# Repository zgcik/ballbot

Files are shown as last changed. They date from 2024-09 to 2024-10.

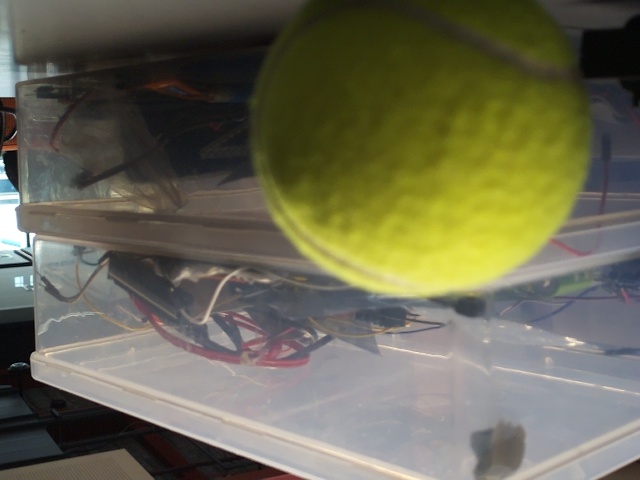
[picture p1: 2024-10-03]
test.jpg

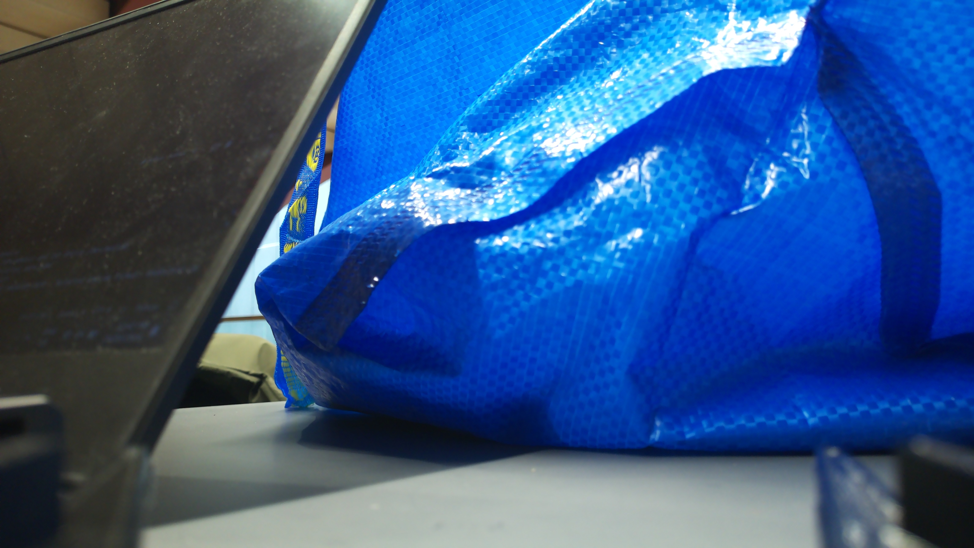
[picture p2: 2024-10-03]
image.jpg

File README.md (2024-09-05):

# ballcollector
ece4191 project overview:

synopsis:
- be able to locate tennis balls contained within its quadrant of the court
- be able to move to a located tennis ball
- be able to pick up located tennis balls
- be able to navigate to a collection box located in the center of the four quadrants of the court
- be able to deposit collected tennis balls in the cardboard collection box of dimensions 60x45x18cm
- may travel into other quadrants of the court momentarily

## Pi Setup

environment initialisation:

```sh
sudo apt-get update && sudo apt-get upgrade -y
sudo apt-get install -y git libgl1
```

To install Python packages:

```sh
python3.11 -m venv .venv
. .venv/bin/activate
pip install -r requirements.txt
```

To get proper headless opencv

```sh
pip uninstall opencv-python && pip install opencv-python-headless==4.10.0.84
```

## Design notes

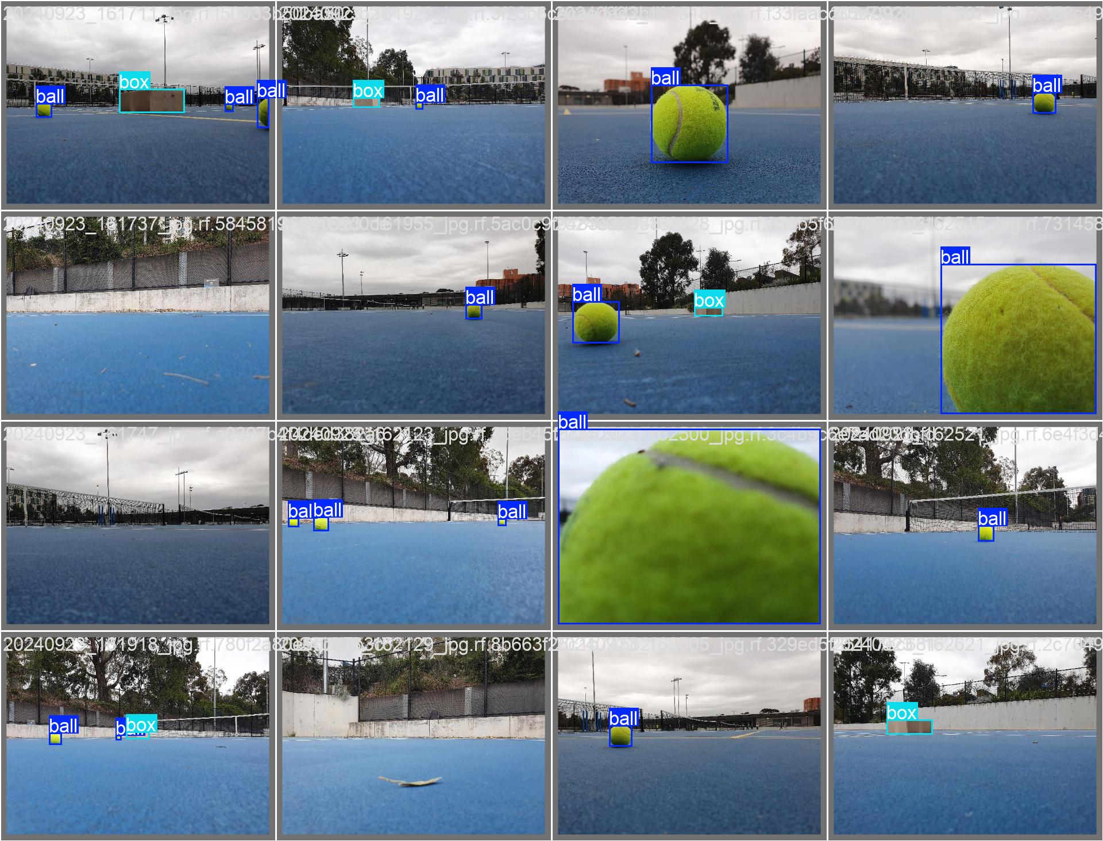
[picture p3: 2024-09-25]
runs/detect/train15/val_batch1_labels.jpg

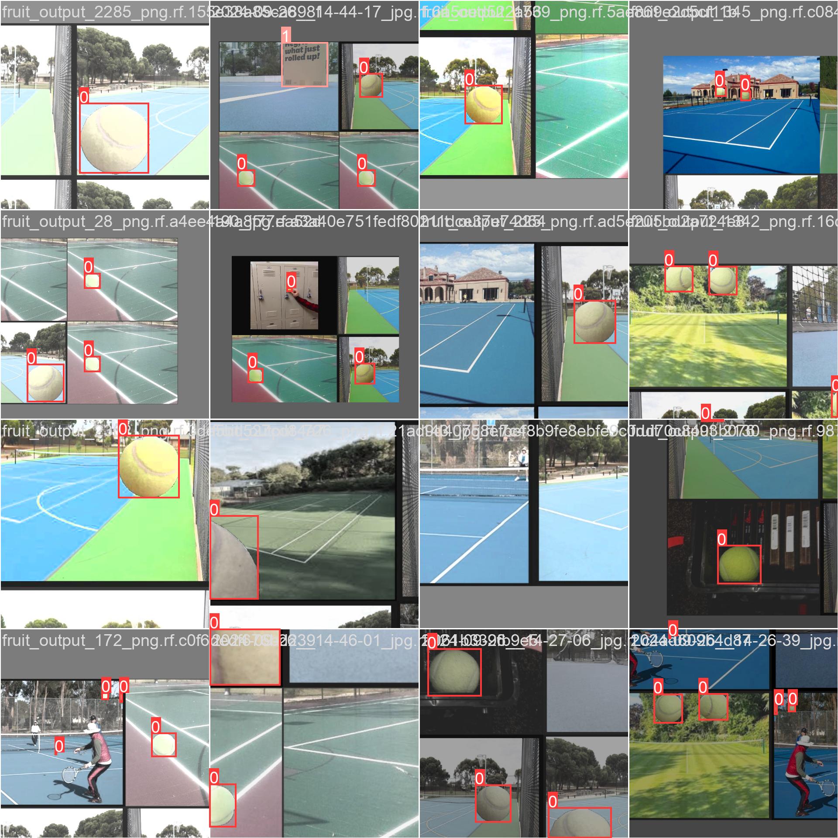
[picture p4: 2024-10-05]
runs/detect/train7/train_batch1.jpg

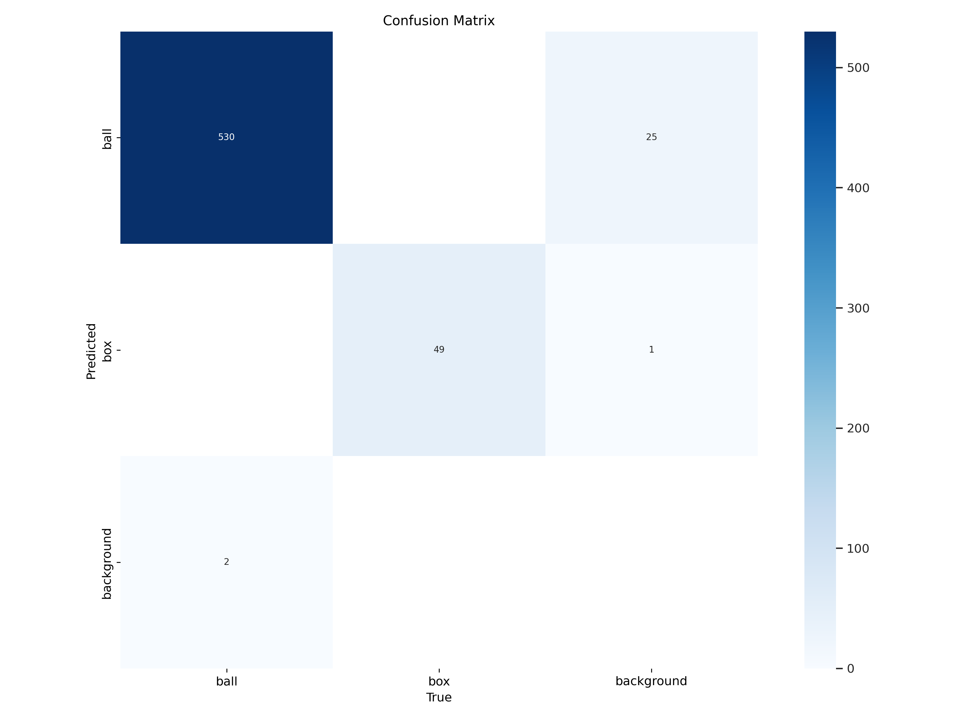
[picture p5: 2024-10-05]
runs/detect/train/confusion_matrix.png

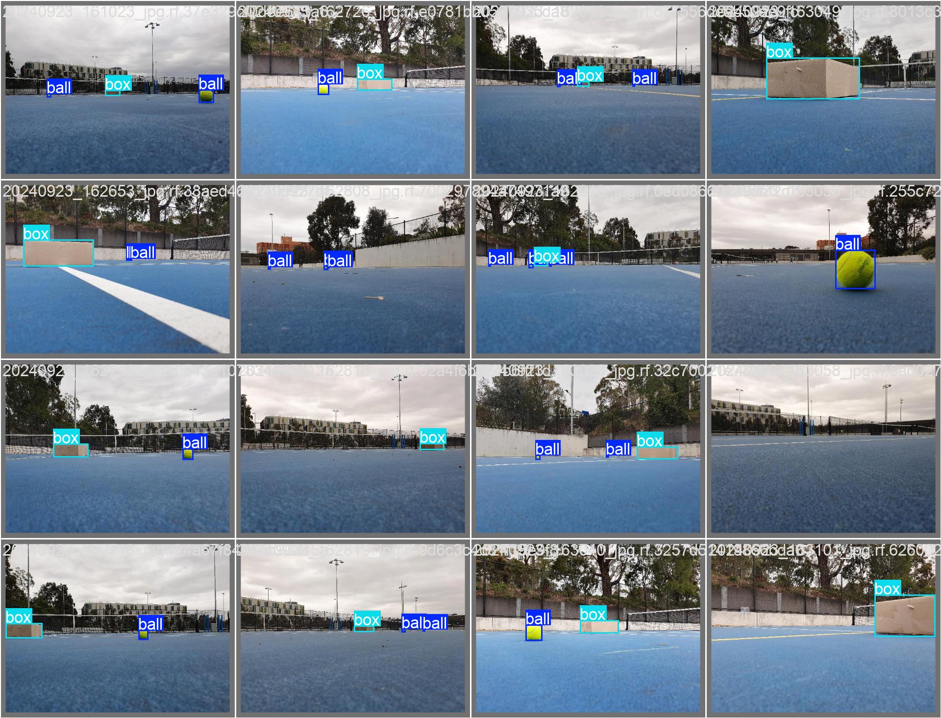
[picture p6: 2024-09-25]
runs/detect/train15/val_batch0_labels.jpg

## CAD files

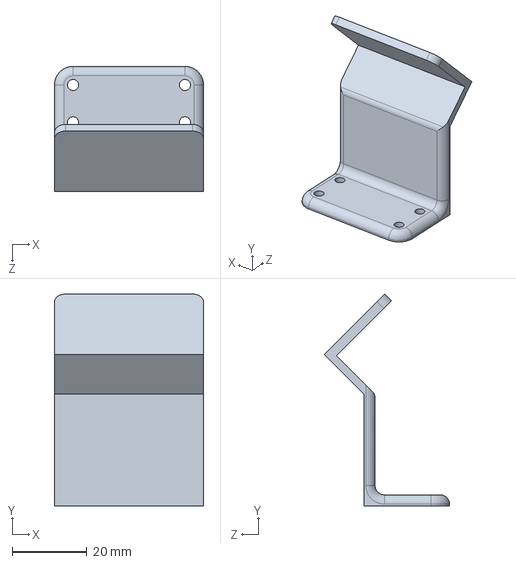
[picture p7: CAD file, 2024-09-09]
cad/camera_mount.SLDPRT
40.0 x 56.9 x 33.6 mm

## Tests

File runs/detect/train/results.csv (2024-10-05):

epoch | train/box_loss | train/cls_loss | train/dfl_loss | metrics/precision(B) | metrics/recall(B) | metrics/mAP50(B) | metrics/mAP50-95(B) | val/box_loss | val/cls_loss | val/dfl_loss | lr/pg0 | lr/pg1 | lr/pg2
1 | 0.61367 | 0.33842 | 0.95513 | 0.99523 | 0.97931 | 0.99433 | 0.86966 | 0.64935 | 0.30115 | 0.94216 | 0.003325 | 0.003325 | 0.003325
2 | 0.61059 | 0.32843 | 0.95129 | 0.9848 | 0.97838 | 0.99421 | 0.87362 | 0.65758 | 0.30609 | 0.94676 | 0.0065925 | 0.0065925 | 0.0065925
3 | 0.62816 | 0.35354 | 0.96345 | 0.98289 | 0.90865 | 0.97053 | 0.8075 | 0.76567 | 0.43233 | 0.99721 | 0.0097939 | 0.0097939 | 0.0097939
4 | 0.6518 | 0.379 | 0.98078 | 0.98427 | 0.97744 | 0.99344 | 0.85778 | 0.6612 | 0.34226 | 0.94969 | 0.009703 | 0.009703 | 0.009703
5 | 0.64245 | 0.37405 | 0.96777 | 0.97595 | 0.9712 | 0.99305 | 0.86137 | 0.67199 | 0.33716 | 0.9478 | 0.009703 | 0.009703 | 0.009703
6 | 0.63782 | 0.36604 | 0.9661 | 0.98228 | 0.97986 | 0.99343 | 0.86088 | 0.67079 | 0.33595 | 0.95544 | 0.009604 | 0.009604 | 0.009604
7 | 0.6386 | 0.36665 | 0.96545 | 0.9803 | 0.98026 | 0.99297 | 0.86126 | 0.66828 | 0.32324 | 0.95229 | 0.009505 | 0.009505 | 0.009505

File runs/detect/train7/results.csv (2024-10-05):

epoch | train/box_loss | train/cls_loss | train/dfl_loss | metrics/precision(B) | metrics/recall(B) | metrics/mAP50(B) | metrics/mAP50-95(B) | val/box_loss | val/cls_loss | val/dfl_loss | lr/pg0 | lr/pg1 | lr/pg2
1 | 0.76893 | 0.59395 | 1.0645 | 0.96094 | 0.85777 | 0.9535 | 0.77543 | 0.75874 | 0.55182 | 1.016 | 0.003325 | 0.003325 | 0.003325
2 | 0.70082 | 0.44292 | 1.0126 | 0.96281 | 0.99436 | 0.99296 | 0.83559 | 0.73942 | 0.38563 | 1.0081 | 0.0065925 | 0.0065925 | 0.0065925
3 | 0.70348 | 0.45006 | 1.0124 | 0.91341 | 0.61337 | 0.65904 | 0.53771 | 0.84154 | 1.0891 | 1.0252 | 0.0097939 | 0.0097939 | 0.0097939
4 | 0.71756 | 0.45166 | 1.0211 | 0.97859 | 0.9718 | 0.99338 | 0.84568 | 0.70422 | 0.43981 | 0.98666 | 0.009703 | 0.009703 | 0.009703
5 | 0.69208 | 0.42383 | 1.0009 | 0.98233 | 0.96493 | 0.99145 | 0.84396 | 0.72122 | 0.36781 | 0.98716 | 0.009703 | 0.009703 | 0.009703
6 | 0.67874 | 0.4068 | 0.99016 | 0.98629 | 0.97956 | 0.99388 | 0.85443 | 0.68921 | 0.35361 | 0.96748 | 0.009604 | 0.009604 | 0.009604
7 | 0.66437 | 0.3903 | 0.98201 | 0.96599 | 0.97852 | 0.98707 | 0.84727 | 0.69616 | 0.3551 | 0.97054 | 0.009505 | 0.009505 | 0.009505

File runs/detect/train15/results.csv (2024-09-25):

epoch | train/box_loss | train/cls_loss | train/dfl_loss | metrics/precision(B) | metrics/recall(B) | metrics/mAP50(B) | metrics/mAP50-95(B) | val/box_loss | val/cls_loss | val/dfl_loss | lr/pg0 | lr/pg1 | lr/pg2
1 | 1.5438 | 3.9237 | 1.3642 | 0.9912 | 0.39344 | 0.40228 | 0.28099 | 1.0747 | 2.433 | 1.329 | 0.0001667 | 0.0001667 | 0.0001667
2 | 0.94781 | 2.1284 | 1.0814 | 0.99475 | 0.39344 | 0.55272 | 0.39317 | 0.79923 | 1.7455 | 1.175 | 0.0003466 | 0.0003466 | 0.0003466
3 | 0.81116 | 1.4123 | 0.99915 | 0.82493 | 0.77443 | 0.81991 | 0.59575 | 0.77673 | 1.061 | 1.0739 | 0.00052288 | 0.00052288 | 0.00052288
4 | 0.76815 | 0.88831 | 0.99235 | 0.84396 | 0.66376 | 0.72995 | 0.59192 | 0.65381 | 0.81629 | 0.95858 | 0.00069552 | 0.00069552 | 0.00069552
5 | 0.71469 | 0.70433 | 0.91393 | 0.9344 | 0.84351 | 0.91063 | 0.73672 | 0.70013 | 0.69426 | 0.96125 | 0.00086453 | 0.00086453 | 0.00086453
6 | 0.69327 | 0.60247 | 0.93357 | 0.9695 | 0.89443 | 0.91805 | 0.7575 | 0.61829 | 0.57087 | 0.92552 | 0.0010299 | 0.0010299 | 0.0010299
7 | 0.68311 | 0.55867 | 0.92514 | 0.99294 | 0.88623 | 0.93327 | 0.7735 | 0.58784 | 0.51704 | 0.91806 | 0.0011917 | 0.0011917 | 0.0011917
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

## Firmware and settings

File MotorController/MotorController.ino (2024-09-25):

#include <Servo.h>

// pin definitions
const int rightEncoderPin = 2; // right motor encoder (interrupt pin)
const int leftEncoderPin = 3;  // left motor encoder (interrupt pin)

const int rightMotorEN = 11;   // right motor enable (PWM pin)
const int rightMotorIn1 = 10;   // right motor direction pin 1
const int rightMotorIn2 = 9;   // right motor direction pin 2

const int leftMotorEN = 6;     // left motor enable (PWM pin)
const int leftMotorIn1 = 8;    // left motor direction pin 1
const int leftMotorIn2 = 7;    // left motor direction pin 2

// Define pins for Ultrasonic Sensor
const int trigPin = 4;      // Trigger pin of the ultrasonic sensor
const int echoPin = 13;      // Echo pin of the ultrasonic sensor

// Variables for distance measurement and counting
int distance = 0;
int count = 0;

// PID class
class PID{
  private:
    float kp;
    float ki;
    float kd;

    float last_error;
    float integral;
    unsigned long last_time;

  public:
  // constructor:
    PID(float kp_in, float ki_in, float kd_in){
      kp = kp_in;
      ki = ki_in;
      kd = kd_in;

      last_error = 0.0;
      integral = 0.0;
      last_time = millis();
    }
  
    float compute(float setpoint, float val){
      unsigned long t = millis();
      float t_elapsed = (t - last_time) / 1000.0;
      
      if (t_elapsed <= 0) return 0;

      // calculate error
      float error = setpoint - val;

      // integral term
      integral += error * t_elapsed;

      // derivative term
      float derivative = (error - last_error) / t_elapsed;

      // update last values
      last_error = error;
      last_time = t;

      // return the control signal
      return (kp * error) + (ki * integral) + (kd * derivative);
    }
};

int ticksPerRevolution = 900; // 900 encoder ticks per revolution
volatile long leftTicks = 0;
volatile long rightTicks = 0;

float baseline = 0.0649805927627767*2;  // default baseline
float wheelRadius = 0.025;  // default wheel radius

Servo myServo;

// interrupt service routine for left encoder
void leftEncoderISR() {
  leftTicks++;
}

// interrupt service routine for right encoder
void rightEncoderISR() {
  rightTicks++;
}


float normalizeAngle(float angle) {
  while (angle > PI) {
    angle -= 2 * PI;
  }
  while (angle < -PI) {
    angle += 2 * PI;
  }
  return angle;
}

// function to drive the left motor at constant speed
void driveLeftMotor(int pwmValue) {
  if (pwmValue > 0){
    digitalWrite(leftMotorIn1, HIGH);
    digitalWrite(leftMotorIn2, LOW);
    analogWrite(leftMotorEN, pwmValue);
  }
  if (pwmValue < 0){
    digitalWrite(leftMotorIn1, LOW);
    digitalWrite(leftMotorIn2, HIGH);
    analogWrite(leftMotorEN, abs(pwmValue));
  }
}


// function to adjust right motor speed based on PID
void driveRightMotor(int pwmValue) {
  if (pwmValue > 0){
    digitalWrite(rightMotorIn1, HIGH);
    digitalWrite(rightMotorIn2, LOW);
    analogWrite(rightMotorEN, pwmValue);
  }
  if (pwmValue < 0){
    digitalWrite(rightMotorIn1, LOW);
    digitalWrite(rightMotorIn2, HIGH);
    analogWrite(rightMotorEN, abs(pwmValue));
  }

}


// function to stop both motors
void stopMotors() {
  digitalWrite(leftMotorIn1, LOW);
  digitalWrite(leftMotorIn2, LOW);
  analogWrite(leftMotorEN, 0);

  digitalWrite(rightMotorIn1, LOW);
  digitalWrite(rightMotorIn2, LOW);
  analogWrite(rightMotorEN, 0);
}

// Function to measure distance using the ultrasonic sensor
int getDistance() {
  // Send a pulse to the trigger pin
  digitalWrite(trigPin, LOW);
  delayMicroseconds(2);
  digitalWrite(trigPin, HIGH);
  delayMicroseconds(10);
  digitalWrite(trigPin, LOW);

  // Measure the duration of the echo pulse
  long duration = pulseIn(echoPin, HIGH);

  // Convert the duration to distance in cm
  int distance = duration * 0.034 / 2;
  
  return distance;
}

PID linPID(5.4, -0.0083, -0.00005);
void drive(float revolutions) {
  long targetTicks = revolutions * ticksPerRevolution;
  leftTicks = 0;
  rightTicks = 0;
  int pwm = 175; // 50%

  while (abs(leftTicks) < abs(targetTicks) && abs(rightTicks) < abs(targetTicks)) {
    if (revolutions > 0){
      // call the PID function to adjust the right motor
      float control = linPID.compute(leftTicks, rightTicks);

      // constrain control signal to valid PWM range
      control = constrain(fabs(control), 100, 250);

      // drive motors
      driveLeftMotor(pwm);  // drive left motor at constant speed
      driveRightMotor(control);  // adjust right motor speed based on PID control
    }
    else if (revolutions < 0){
       // call the PID function to adjust the right motor
      float control = linPID.compute(leftTicks, rightTicks);

      // constrain control signal to valid PWM range
      control = constrain(fabs(control), pwm-5, 250);

      // drive motors
      driveLeftMotor(-pwm);  // drive left motor at constant speed
      driveRightMotor(-control);  // adjust right motor speed based on PID control

    }
  }

  // output encoder ticks to the serial monitor
  Serial.print("L:");
  Serial.print((float)leftTicks/(float)ticksPerRevolution);
  Serial.print(",R:");
  Serial.println((float)rightTicks/(float)ticksPerRevolution);

  Serial.print("error left:");
  Serial.println(abs((float)leftTicks-(float)targetTicks)/((float)targetTicks));

  Serial.print("error right:");
  Serial.println(abs((float)rightTicks-(float)targetTicks)/((float)targetTicks));

  // stop motors when done
  stopMotors();
}

// turn function
PID rotPID(5.4, 0.0125, -0.015);
void turn(float radians) {
  // normalize the angle to [-pi, pi]
  radians = normalizeAngle(radians);
  
  // calculate the number of wheel rotations required to turn the robot by the specified angle
  float distanceToTravel = (abs(radians) * baseline/2);  // arc length for one wheel
  float wheelRotations = distanceToTravel / (PI * wheelRadius);  // required wheel rotations
  long targetTicks = wheelRotations * ticksPerRevolution/2;  // convert to encoder ticks

  // reset the encoder ticks
  leftTicks = 0;
  rightTicks = 0;

  int pwm = 130;

  // perform the turn
  if (radians > 0) {
    // turning right
    while (abs(leftTicks) < targetTicks && abs(rightTicks) < targetTicks) {
      float control = rotPID.compute(abs(leftTicks), abs(rightTicks));
      control = constrain(abs(control), 75, 250);

      driveLeftMotor(pwm);
      driveRightMotor(-control);
      
    }
  } else if (radians < 0) {
    // turning left
    while (abs(leftTicks) < targetTicks && abs(rightTicks) < targetTicks) {
      float control = rotPID.compute(abs(leftTicks), abs(rightTicks));
      control = constrain(abs(control), 75, 250);

      driveLeftMotor(-pwm);
      driveRightMotor(control);
    }
  }

  // output encoder ticks to the serial monitor
  Serial.print("L:");
  Serial.print((float)leftTicks/(float)ticksPerRevolution);
  Serial.print(",R:");
  Serial.println((float)rightTicks/(float)ticksPerRevolution);

  Serial.print("error left:");
  Serial.println(abs((float)leftTicks-(float)targetTicks)/((float)targetTicks));

  Serial.print("error right:");
  Serial.println(abs((float)rightTicks-(float)targetTicks)/((float)targetTicks));

  // stop both motors after the turn is completed
  stopMotors();
}


// function to move the servo incrementally by 10 degrees
void moveServo(int dt, int targetAngle) {
  int currentAngle = myServo.read();  // get the current angle of the servo
  
  if (targetAngle > currentAngle) {
    // incrementally move the servo up to the target angle
    for (int angle = currentAngle; angle <= targetAngle; angle += 10) {
      myServo.write(angle);
      delay(dt);  // wait for the given time step
    }
  } else {
    // decrementally move the servo down to the target angle
    for (int angle = currentAngle; angle >= targetAngle; angle -= 10) {
      myServo.write(angle);
      delay(dt);  // wait for the given time step
    }
  }
}


void setup() {
  // set up motor control pins as outputs
  pinMode(rightMotorIn1, OUTPUT);
  pinMode(rightMotorIn2, OUTPUT);
  pinMode(rightMotorEN, OUTPUT);

  pinMode(leftMotorIn1, OUTPUT);
  pinMode(leftMotorIn2, OUTPUT);
  pinMode(leftMotorEN, OUTPUT);

  // Set ultrasonic sensor pins
  pinMode(trigPin, OUTPUT);
  pinMode(echoPin, INPUT);

  // set motors to stopped state at the start
  stopMotors();
  // set up encoder pins as inputs
  pinMode(rightEncoderPin, INPUT);
  pinMode(leftEncoderPin, INPUT);

  //Servo 
  myServo.attach(5);  // attach the servo to pin 11
  myServo.write(7);    // initialize the servo at 0 degrees

  // attach interrupts for encoder reading
  attachInterrupt(digitalPinToInterrupt(leftEncoderPin), leftEncoderISR, RISING);
  attachInterrupt(digitalPinToInterrupt(rightEncoderPin), rightEncoderISR, RISING);

  Serial.begin(9600); // initialize serial communication at 9600 baud
}

void loop() {
  delay(1000);
  
  if (Serial.available() > 0) {
    String input = Serial.readStringUntil('\n');  // read input from serial

    // check if the input is for PID tuning
    // Check if the input starts with "$Drive:"
    if (input.startsWith("$drive:")) {
      String revStr = input.substring(7);  // extract substring after "$Drive:"
      int indexOfRev = revStr.indexOf("rev");
      if (indexOfRev != -1) {
        revStr = revStr.substring(0, indexOfRev);  // extract the number part
        revStr.trim();  // trim any whitespace
        float rev = revStr.toFloat();
        if (rev > 0) {
          drive(rev);  // call the drive function with the extracted number of revolutions
        } else {
          //Serial.println("error: invalid number of revolutions.");
          drive(rev);
        }
      } else {
        Serial.println("error: invalid command format.");
      }
    }
    // check if the input starts with "$Turn:"
    else if (input.startsWith("$turn:")) {
      String radStr = input.substring(6);  // extract substring after "$Turn:"
      int indexOfRad = radStr.indexOf("rad");
      if (indexOfRad != -1) {
        radStr = radStr.substring(0, indexOfRad);  // extract the radians part
        radStr.trim();  // trim any whitespace
        float radians = radStr.toFloat();  // can handle negative values
        Serial.println(radians);
        turn(radians);  // call the turn function with the extracted angle in radians
      } else {
        Serial.println("error: invalid command format.");
      }
    }
    // check if the input starts with "$SetBaseline:"
    else if (input.startsWith("$setBaseline:")) {
      int commandLength = 13;  // length of "$setBaseline:"
      String baselineStr = input.substring(commandLength);  // extract the number after "$setBaseline:"
      baselineStr.trim();  // trim any whitespace
      float newBaseline = baselineStr.toFloat();  // convert to float
      if (newBaseline > 0) {
        baseline = newBaseline;  // update the baseline
      } else {
        Serial.println("error: invalid baseline value.");
      }
    }
    // check if the input starts with "$SetWheelRadius:"
    else if (input.startsWith("$setWheelRadius:")) {
      int colonIndex = input.indexOf(':');
      if (colonIndex != -1 && colonIndex + 1 < input.length()) {
        String wheelRadiusStr = input.substring(colonIndex + 1);  
        wheelRadiusStr.trim();  // trim any whitespace
        float newWheelRadius = wheelRadiusStr.toFloat();  
        if (newWheelRadius > 0) {
          wheelRadius = newWheelRadius;  // update the wheel radius
        } else {
          Serial.println("error: invalid wheel radius value.");
        }
      } else {
        Serial.println("error: invalid command format.");
      }
    }
    // ceck if the input starts with "$Flip Theta"
    else if (input.startsWith("$flip:")) {
      int indexOfTheta = input.indexOf("theta");
      int indexOfDT = input.indexOf("DT");
      if (indexOfTheta != -1 && indexOfDT != -1) {
        String thetaStr = input.substring(indexOfTheta + 6, indexOfDT - 1);  // extract the angle part
        String dtStr = input.substring(indexOfDT + 3);  // extract the time step part
        thetaStr.trim();
        dtStr.trim();
        int targetAngle = thetaStr.toInt();  // convert to integer
        int dt = dtStr.toInt();  // convert to integer
        if (targetAngle > 0 && dt > 0) {
          moveServo(dt, targetAngle);  // move the servo to the target angle
          delay(1000);  // wait for 1 second
          moveServo(dt, 0);  // move the servo back to 0 degrees
          moveServo(dt, 7);
        } else {
          Serial.println("error: invalid theta or DT values.");
        }
      } else {
        Serial.println("error: invalid flip command format.");
      }
    } 
    
    else if(input.startsWith("$Ultrasonic:")){
      // Get the distance from the ultrasonic sensor
      distance = getDistance();
      
      // Print the distance to the Serial Monitor
      Serial.print("Distance: ");
      Serial.print(distance);
      Serial.println(" cm");
      while (distance >=5){
        // Check if the distance is less than 30 cm
        if (distance < 30) {
          count++;  // Increment count if the distance is less than 30 cm
        } else {
          count = 0;  // Reset count if the distance is more than 30 cm
        }

        // If the count exceeds 5, move the robot backward
        if (count >= 5) {
          drive(-1);
          count = 0;  // Reset count after moving backward
        }

        // Delay to allow some time between measurements
        delay(1000);
      }
    } else {
      Serial.println("error: unrecognized command.");
    }
  }
}


// function to drive the robot a certain number of revolutions

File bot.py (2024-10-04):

import time
import serial
import numpy as np

from camera import Camera
import math
class Bot:
    def __init__(self):
        # Calibration
        self.wheel = 0.05415049396898059
        self.baseline = 0.023

        # Init robot state
        self.state = [0.0, 0.0, 0.0]

        # Init cam
        self.cam = Camera(device=0)

        # Setting up Arduino communication
        self.arduino_port = '/dev/ttyACM1'
        self.baud_rate = 9600

        # Open the serial connection during initialization
        self.ser = None
        self.setup_arduino()

        self.d = 1000
        self.t = 1000

        self.wheelrad = 0.024
        self.baseline = 0.2666

    def setup_arduino(self):
        # Try connecting to /dev/ttyACM1 first, if it fails, try /dev/ttyACM0
        possible_ports = ['/dev/ttyACM1', '/dev/ttyACM0']

        for port in possible_ports:
            try:
                print(f"Trying to connect to {port}...")
                self.ser = serial.Serial(port, self.baud_rate, timeout=1)
                time.sleep(2)  # Give Arduino time to initialize
                self.ser.flushInput()
                self.ser.flushOutput()
                print(f"Successfully connected to {port}.")
                return  # Exit the method if successful
            except serial.SerialException as e:
                print(f"Error in serial communication setup on {port}: {e}")

        # If no port works, set self.ser to None
        print("Failed to connect to any serial port.")
        self.ser = None

    def restart_serial(self):
        print("Restarting the serial connection...")
        self.setup_arduino()

    def send_command(self, command):
        if self.ser is None or not self.ser.is_open:
            print("Serial connection not established or lost.")
            self.restart_serial()  # Restart the serial connection
            return None

        while True:
            try:
                # Send command
                print(f"Sending command: {command}")
                self.ser.write(f"{command}\n".encode())
                time.sleep(0.5)  # Give Arduino time to process
                # Call received to read the response
                return self.received()

            except (serial.SerialException, OSError) as e:
                print(f"Error in serial communication: {e}")
                time.sleep(0.5)
                self.restart_serial()  # Restart the serial connection on error
                return None

    def received(self):
        """Listens to the serial and checks for '$done' message with a timeout of 2 seconds."""
        if self.ser is None:
            return None

        start_time = time.time()  # Record the current time to track timeout
        timeout_duration = 15 # Timeout after 2 seconds

        while True:
            if self.ser.in_waiting > 0:  # Check if data is available to read
                response = self.ser.readline().decode().strip()
                print(f"Received: {response}")  # Print the received response for debugging
                if "$done" in response:  # Check if $done is part of the response
                    print("Command complete.")
                    return response
                elif "Left" in response:
                    self.update_state(response) 

            # Check if the loop has exceeded the timeout duration
            if time.time() - start_time > timeout_duration:
                print("Timeout: No response from Arduino after 2 seconds.")
                return "Timeout"

            time.sleep(0.1)  # Small delay to prevent CPU overload
    
    def update_state(self, response):
        parts = response.split()
        left_ticks = int(parts[2])
        right_ticks = int(parts[5])
        d_L = (left_ticks / 900) * 2 * math.pi * self.wheelrad # Left wheel distance
        d_R = (right_ticks / 900) * 2 * math.pi * self.wheelrad  # Right wheel distance

        # Step 2: Calculate change in orientation (Δθ)
        delta_theta = (d_L - d_R ) / self.baseline

        # Step 3: Calculate average distance traveled
        avg_distance = (d_L + d_R) / 2

        # Step 4: Calculate change in position (Δx, Δy)
        if delta_theta == 0:  # Robot is moving straight
            delta_x = avg_distance * math.cos(self.state[2])
            delta_y = avg_distance * math.sin(self.state[2])
            self.state[2] += delta_theta
            self.state[2] = (self.state[2]  + math.pi) % (2 * math.pi) - math.pi
        else:  # Robot is turning
            delta_x = avg_distance * math.cos(self.state[2] + delta_theta / 2)
            delta_y = avg_distance * math.sin(self.state[2] + delta_theta / 2)
            self.state[2] += delta_theta
            self.state[2] = (self.state[2]  + math.pi) % (2 * math.pi) - math.pi

        # Step 5: Update the robot's position and orientation
        self.state[0] +=delta_x
        self.state[1] += delta_y
        print(f"New State X: {self.state[0]}, Y: {self.state[1]}, Theta: {self.state[2]}")


    def __calc_revs__(self, dis):
        return dis / (np.pi * self.wheel)

    def __revs_to_dis__(self, revs):
        return revs * (np.pi * self.wheel)
    
    def __calc_dis__(self, point):
        return np.sqrt((point[0] - self.state[0])**2 + (point[1] - self.state[1])**2)
    
    def __calc_ang__(self, point):
        ang = np.arctan2(point[1] - self.state[1], point[0] - self.state[0])
        ang = (ang - self.state[2]) % (2 * np.pi)
        if ang > np.pi: ang -= 2*np.pi
        return ang
    
    def drive_to_box(self, point):
        dis = self.__calc_dis__(point)
        ang = self.__calc_ang__(point)

        while dis > 0.2:
            if abs(ang) > 0.005: self.rotate(ang)
            self.drive(1.0)

            # recalculating position
            dis = self.__calc_dis__(point)
            ang = self.__calc_ang__(point)
        
    def drive_to_target(self):
        self.d = 1000
        self.t = 1000
        while True: #True
            try:
                time.sleep(0.2)
                d, t = self.cam.detect_closest()
                self.d = d
                self.t = t
            except:
                print('error: ball not found')
                if self.d <= 0.2 and abs(self.t) < 0.2:
                    return True
                else:
                    return False
            print(f"distance: {d}, angle: {t}")
            if abs(t) > 0.05: 
                self.rotate(t/2)
            print(d <= 0.2 and abs(t) < 0.2)
            if d >= 1:
                self.drive(2)
            elif d >= 0.5 and d < 1:
                self.drive(0.5)
            elif d > 0.35:
                self.drive(0.25)
            elif d > 0.2 and d < 0.35:
                self.drive(0.35)
                return True
            elif d <= 0.2 and abs(t) < 0.2:
                return True
            # time.sleep(1.5)
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

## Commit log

2024-09-08 new camera calibration
2024-09-08 camera and main functions completed
2024-09-08 camera calibration completed
2024-09-09 added camera mount part file
    [camera_mount.SLDPRT]
2024-09-20 added arduino setup
2024-09-22 changes to motor controller arduino integration
2024-09-22 Changed Pin numbers
2024-09-23 arduino fixes
2024-09-23 Add files via upload
    23/09 Update Improved PID
2024-09-23 train custom yolo
    [results.csv]
2024-09-25 added calibration and fixed rev calculation method
    [bot.py, cam_calibration.py, drive_calibration.py]
2024-09-25 ammended drive calibration
2024-09-25 added calibration
2024-09-25 added PID config
2024-10-05 train new model
    [results.csv]
2024-10-05 update camera code
